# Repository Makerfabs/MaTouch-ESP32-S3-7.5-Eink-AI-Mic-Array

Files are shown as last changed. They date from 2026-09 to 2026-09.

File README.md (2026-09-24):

# MaTouch ESP32-S3 7.5 Eink AI Mic Array

## Introduction

Our MaTouch ESP32-S3 7.5-inch Quad-color E-Ink Display AI Microphone Array Development Board features a 7.5-inch quad-color e-paper display supporting black, white, red, and yellow color rendering. Based on microcapsule electrophoretic display technology, the screen drives charged pigment particles within microcapsules using electric fields, reflecting ambient light to form sharp images that deliver a natural reading experience similar to printed paper.
 
The board is powered by the ESP32-S3R8 main controller, equipped with 8 MB PSRAM and 16 MB SPI Flash. It integrates a four-microphone array and an ES7210 multi-channel audio ADC, enabling multi-channel audio capture for voice recognition, far-field sound pickup, and acoustic algorithm development. Additionally, it includes a QMI8658A six-axis inertial measurement unit providing accelerometer and gyroscope data for motion detection, orientation sensing, and interactive control. The board also features a camera, TF card slot, USB Type-C interface, lithium battery charging circuit, and reserved battery level monitoring functionality, making it ideal for application development in e-paper displays, image capture, voice interaction, and motion sensing.

Product Link: [MaTouch ESP32-S3 7.5 Eink AI Mic Array]

Wiki Link:  [MaTouch ESP32-S3 7.5 Eink AI Mic Array](https://wiki.makerfabs.com/MaTouch%20ESP32_S3%207.5%20Eink%20AI%20Mic%20Array.html)

Example：1.[Camera_display_pic](https://github.com/Makerfabs/MaTouch-ESP32-S3-7.5-Eink-AI-Mic-Array#camera_display_pic)

2.[Voice_EPD_SD_Display](https://github.com/Makerfabs/MaTouch-ESP32-S3-7.5-Eink-AI-Mic-Array#voice_epd_sd_display)

## LCD Specs:

- PART NUMBER:KEGM075004E05
- SIZE:7.5 inch
- TYPE:Dot Matrix
- IC：JD79665
- RESOULUTION:800×480
- OUTLINE SIZE(mm):170.2×135.2×1.111
- ACTIVE SIZE(mm):163.2×97.92
- PIXEL PITCH(mm):0.204×0.204
- OPERATING TEMP:0°C ~ 40°C
- STORAGE TEMP:-25°C ~ 60°C
- CONNECTOR:24 Pin FPC
- COLOR:Black,White,Red,Yellow
- INTERFACE:SPI
- FULL REFRESH(S):20

## Features

- Controller:ESP32-S3
- Wireless:WiFi&Bluetooth 5.0
- Flash:16MB Flash
- PSRAM:8MB
- MICRO SD:Yes
- IMU:QMI8658A
- Camera:OV3660
- Microphone input:4-Microphone Array
- Audio ADC:ES7210
- USB:1*USB_NATIVE
- Arduino support:Yes

## Example

### Camera_display_pic

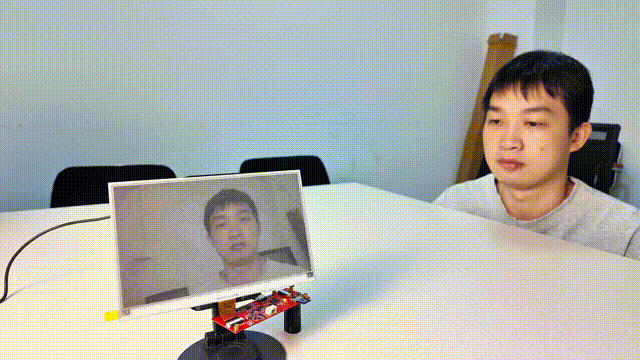
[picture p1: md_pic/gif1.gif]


For details of this example, please refer to the [Wiki](https://wiki.makerfabs.com/MaTouch%20ESP32_S3%207.5%20Eink%20AI%20Mic%20Array.html#41-camera_display_pic) document.

### Voice_EPD_SD_Display

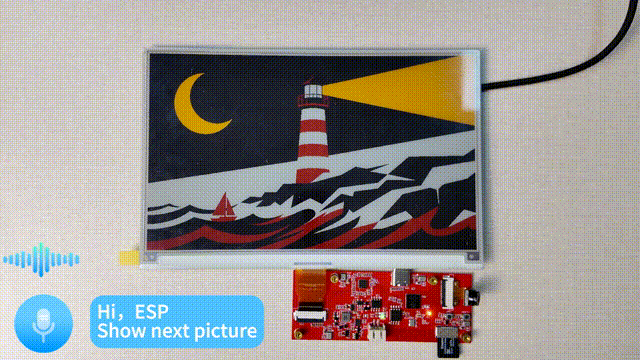
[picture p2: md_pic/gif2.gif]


For details of this example, please refer to the [Wiki](https://wiki.makerfabs.com/MaTouch%20ESP32_S3%207.5%20Eink%20AI%20Mic%20Array.html#42-voice_epd_sd_display) document.

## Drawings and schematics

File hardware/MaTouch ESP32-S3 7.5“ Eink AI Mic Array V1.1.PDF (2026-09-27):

EINK | Mic Array
MIC4P | 28 REFP³⁴ 29 REFQ³⁴ 30

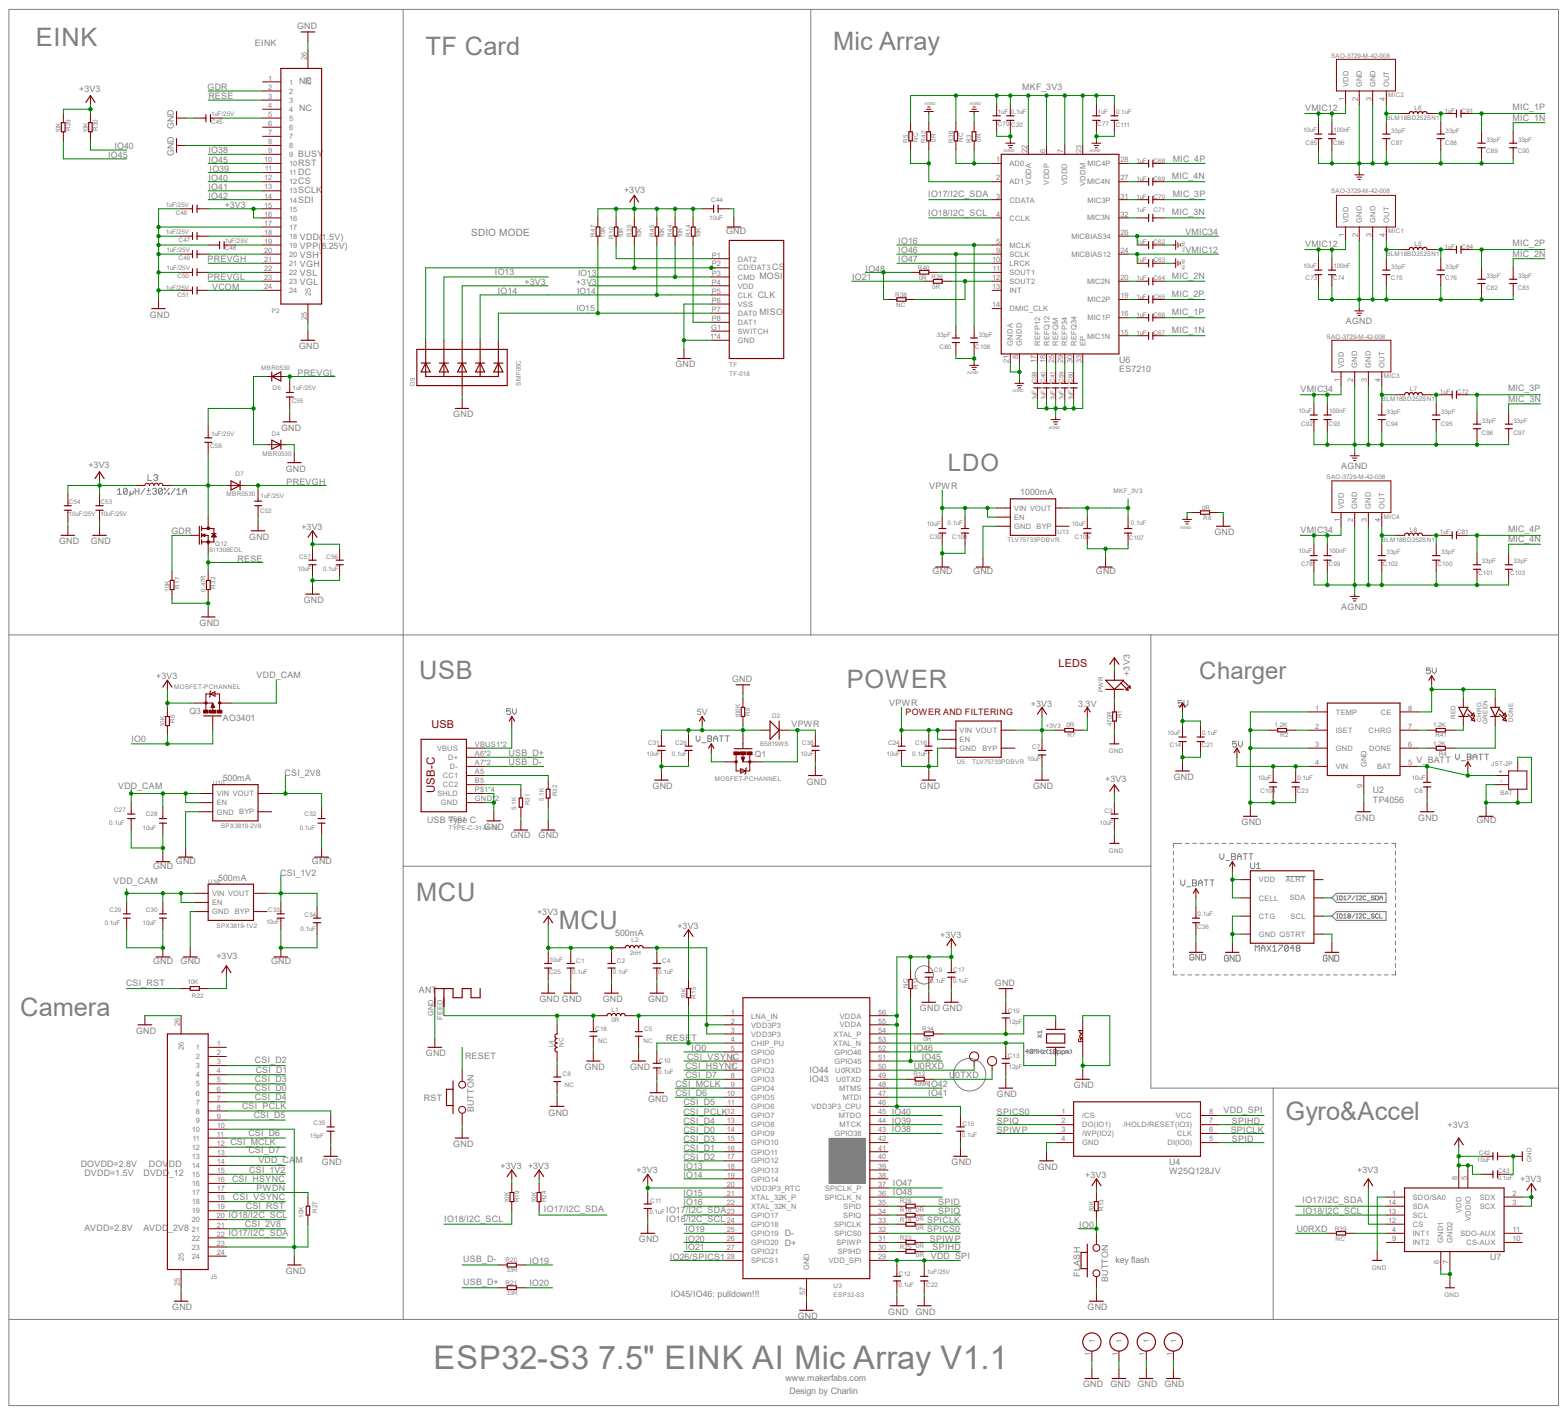
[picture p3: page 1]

SDIO MODE TF Card

key flash ESP32-S3 7.5" EINK AI Mic Array V1.1

GND GND

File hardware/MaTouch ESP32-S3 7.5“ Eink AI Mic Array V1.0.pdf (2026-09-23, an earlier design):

# LDO

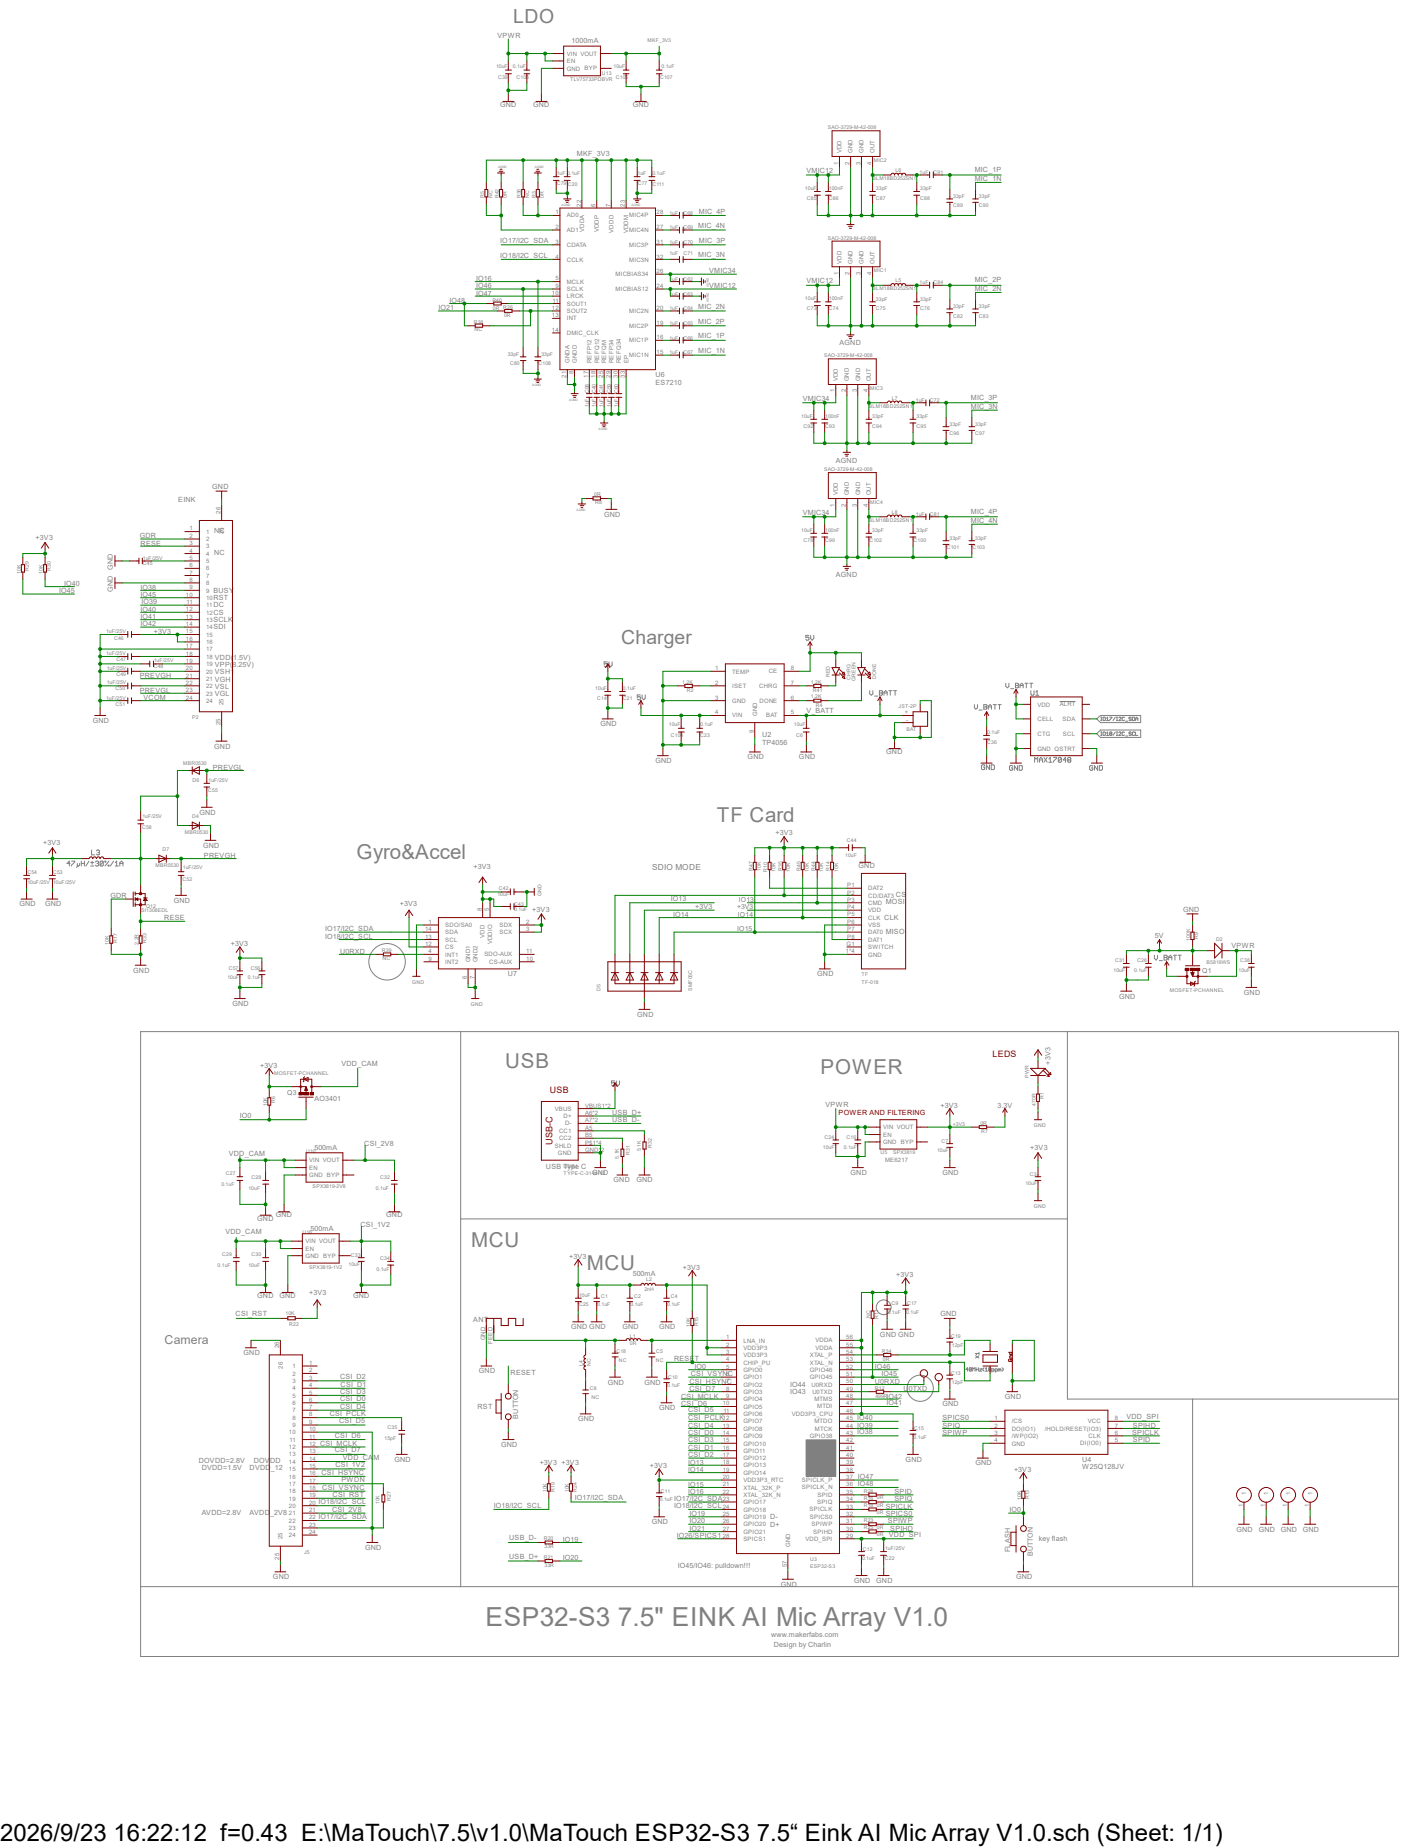
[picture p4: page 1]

RESET C8 NC +3V3 +3V3 | CSI_PCLK CSI_D5 | 2 | 55

GND GND

USB_D-
ESP32-S3 7.5" EINK AI Mic Array V1.0

2026/9/23 16:22:12 f=0.43 E:\MaTouch\7.5\v1.0\MaTouch ESP32-S3 7.5“ Eink AI Mic Array V1.0.sch (Sheet: 1/1)

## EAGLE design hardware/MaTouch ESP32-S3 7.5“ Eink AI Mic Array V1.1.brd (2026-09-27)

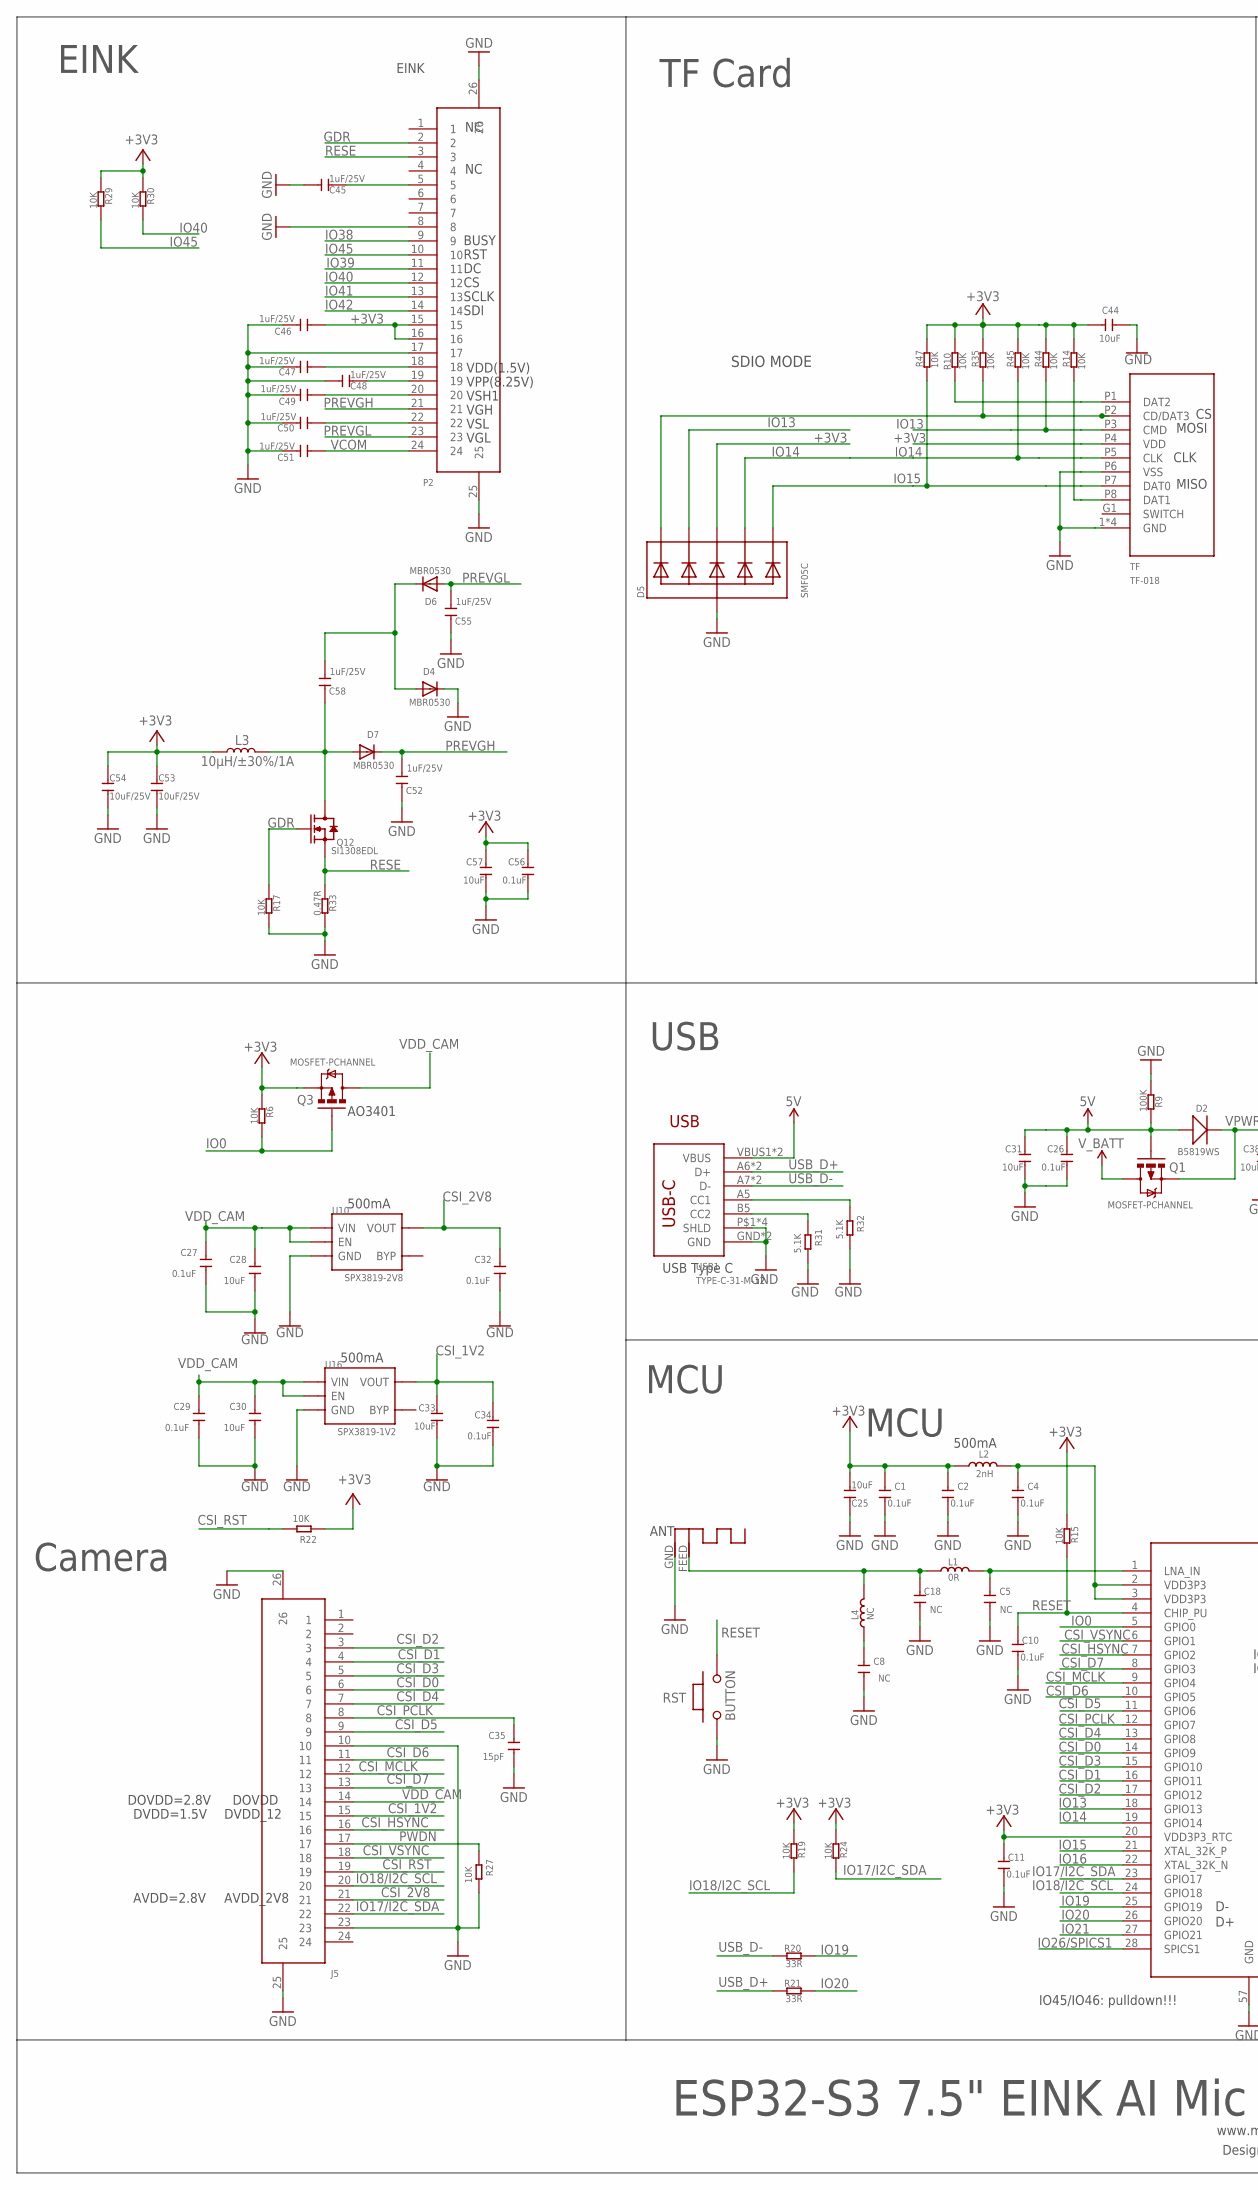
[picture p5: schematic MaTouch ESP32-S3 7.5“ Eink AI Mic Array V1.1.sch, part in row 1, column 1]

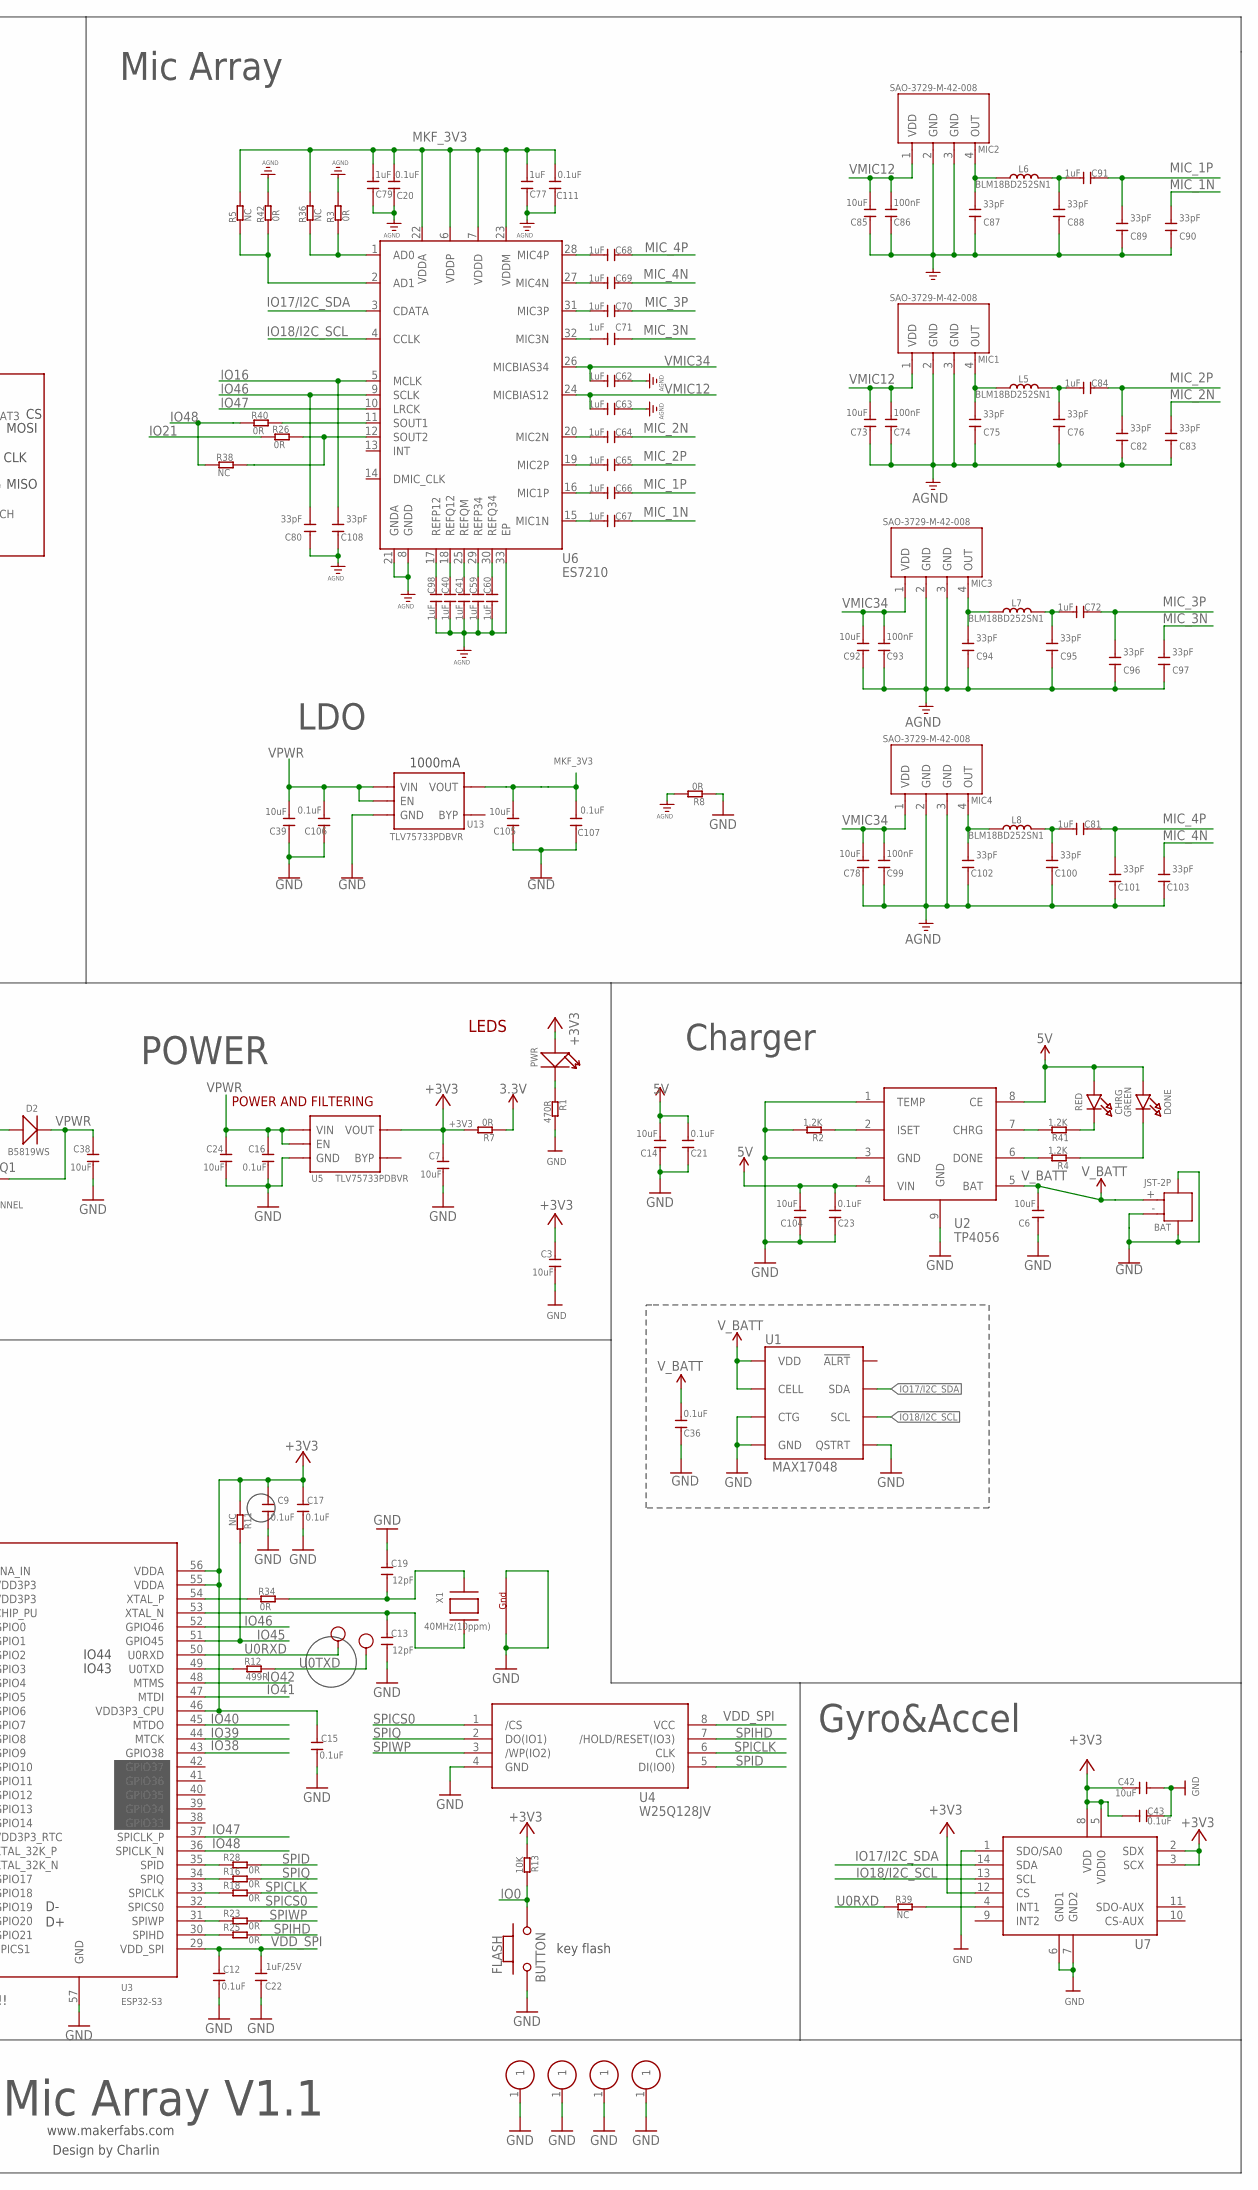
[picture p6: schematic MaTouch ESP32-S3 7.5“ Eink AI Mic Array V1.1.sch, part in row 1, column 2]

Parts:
ANT1: ANTENNA; RN-ANT
BAT: JST-2P; HW2-SMD-2.0-90D
C1, C2, C4, C9, C10, C11, C12, C15, C16, C17, C20, C21, C23, C26, C27, C29, C32, C34, C36, C43, C56, C106, C107, C111: 0.1uF; DISCRETE_C0402
C3, C6, C7, C14, C24, C28, C30, C31, C33, C38, C39, C42, C44, C57, C73, C78, C85, C92, C104, C105: 10uF; DISCRETE_C0402
C5, C8, C18: NC; DISCRETE_C0402
C13, C19: 12pF; DISCRETE_C0402
C22, C45, C46, C47, C48, C49, C50, C51, C52, C55, C58: 1uF/25V; DISCRETE_C0402
C25: 10uF; DISCRETE_C0603
C35: 15pF; DISCRETE_C0402
C40, C41, C59, C60, C62, C63, C64, C65, C66, C67, C68, C69, C70, C71, C72, C77, C79, C81, C84, C91, C98: 1uF; DISCRETE_C0402
C53, C54: 10uF/25V; C0603
C74, C86, C93, C99: 100nF; DISCRETE_C0402
C75, C76, C80, C82, C83, C87, C88, C89, C90, C94, C95, C96, C97, C100, C101, C102, C103, C108: 33pF; DISCRETE_C0402
CHRG: RED; CHIPLED_0805_NOOUTLINE
D2: B5819WS; SOD323
D4, D6, D7: MBR0530; SOD-323F
D5: SMF05C; SOT363
DONE: GREEN; CHIPLED_0805_NOOUTLINE
FLASH: BUTTON; 157SW
J5: FPC-24P; SMD26-50P-1760L450W
L1: 0R; DISCRETE_L0402
L2: 2nH; DISCRETE_L0603
L3: 10µH/±30%/1A; CR54
L4: NC; DISCRETE_L0402
L5, L6, L7, L8: BLM18BD252SN1; L0603
MIC1, MIC2, MIC3, MIC4: SAO-3729-M-42-008; MIC4-SMD-3.76X2.95MM
P2: FPC-24P; SMD26-50P-1760L450W
PWR: DISCRETE_LED0603; DISCRETE_LED-0603
Q1, Q3: MOSFET-PCHANNEL; SOT23-3
Q12: SI1308EDL; SOT23
R1: 470R; DISCRETE_R0402
R2, R4, R41: 1.2K; DISCRETE_R0402
R3, R7, R8, R16, R18, R23, R25, R26, R28, R34, R40, R42: 0R; DISCRETE_R0402
R5, R11, R36, R38, R39: NC; DISCRETE_R0402
R6, R10, R13, R14, R15, R17, R19, R22, R24, R27, R29, R30, R35, R44, R45, R47: 10K; DISCRETE_R0402
R9: 100K; DISCRETE_R0402
R12: 499R; DISCRETE_R0402
R20, R21: 33R; DISCRETE_R0402
R31, R32: 5.1K; DISCRETE_R0402
R33: 0.47R; DISCRETE_R0402
RST: BUTTON; 157SW
RX: TEST-POINT'4545'; TP-D45MIL; PARTNO DNP
S1, S2, S3, S4: ONEPIN01
TF: TF-018
TX: TEST-POINT'4545'; TP-D45MIL; PARTNO DNP
U1: MAX17048; DFN-8
U2: TP4056; SOP8-1.27P
U3: ESP32-S3; QFN56-7*7MM
U4: W25Q128JV; SOIC-8-208MIL
U5, U13: TLV75733PDBVR; SOT23-5
U6: ES7210; QFN33-40P400L400W75H-280X280
U7: QMI8658A; LGA14-50P-300L250W86H
U10: SPX3819-2V8; SOT23-5
U16: SPX3819-1V2; SOT23-5
USB1: TYPE-C-31-M-12
X1: 40MHz(10ppm); NX3225

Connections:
3.3V: R7.2
5V: C14.1, C21.1, C23.1, C26.2, C31.2, C104.1, CHRG.A, D2.+, DONE.A, Q1.1 (G), R9.2, U2.4 (VIN), U2.8 (CE), USB1.VBUS1 (VBUS), USB1.VBUS2 (VBUS)
+3V3: C1.2, C2.2, C3.2, C7.2, C9.2, C11.2, C15.2, C17.2, C25.2, C42.2, C43.2, C44.2, C46.1, C53.1, C54.1, C56.2, C57.2, D5.4 (C3), L2.1, L3.P$1 (1), P2.15, P2.16, PWR.+, Q3.2 (S), R6.2, R7.1, R10.2, R11.2, R13.2, R14.2, R15.2, R19.2, R22.1, R24.2, R29.1, R30.1, R35.2, R44.2, R45.2, R47.2, TF.P4 (VDD), U3.20 (VDD3P3_RTC), U3.46 (VDD3P3_CPU), U3.55 (VDDA), U3.56 (VDDA), U5.5 (VOUT), U7.2 (SDX), U7.3 (SCX), U7.5 (VDDIO), U7.8 (VDD), U7.12 (CS)
AGND: C20.2, C40.2, C41.2, C59.2, C60.2, C62.1, C63.1, C73.2, C74.2, C75.2, C76.2, C77.2, C78.2, C79.2, C80.2, C82.2, C83.2, C85.2, C86.2, C87.2, C88.2, C89.2, C90.2, C92.2, C93.2, C94.2, C95.2, C96.2, C97.2, C98.2, C99.2, C100.2, C101.2, C102.2, C103.2, C108.2, C111.2, MIC1.2 (GND), MIC1.3 (GND), MIC2.2 (GND), MIC2.3 (GND), MIC3.2 (GND), MIC3.3 (GND), MIC4.2 (GND), MIC4.3 (GND), R3.1, R8.1, R42.1, U6.8 (GNDD), U6.21 (GNDA), U6.33 (EP)
CSI_1V2: C33.2, C34.2, J5.15, U16.5 (VOUT)
CSI_2V8: C32.2, J5.21, U10.5 (VOUT)
CSI_D0: J5.6, U3.14 (GPIO9)
CSI_D1: J5.4, U3.16 (GPIO11)
CSI_D2: J5.3, U3.17 (GPIO12)
CSI_D3: J5.5, U3.15 (GPIO10)
CSI_D4: J5.7, U3.13 (GPIO8)
CSI_D5: J5.9, U3.11 (GPIO6)
CSI_D6: J5.11, U3.10 (GPIO5)
CSI_D7: J5.13, U3.8 (GPIO3)
CSI_HSYNC: J5.16, U3.7 (GPIO2)
CSI_MCLK: J5.12, U3.9 (GPIO4)
CSI_PCLK: C35.2, J5.8, U3.12 (GPIO7)
CSI_RST: J5.19, R22.2
CSI_VSYNC: J5.18, U3.6 (GPIO1)
GDR: P2.2, Q12.1 (G), R17.1
GND: ANT1.GND, BAT.3, BAT.4, BAT.- (2), C1.1, C2.1, C3.1, C4.1, C5.1, C6.2, C7.1, C8.1, C9.1, C10.1, C11.1, C12.1, C13.1, C14.2, C15.1, C16.1, C17.1, C18.1, C19.2, C21.2, C22.2, C23.2, C24.1, C25.1, C26.1, C27.1, C28.1, C29.1, C30.1, C31.1, C32.1, C33.1, C34.1, C35.1, C36.2, C38.1, C39.2, C42.1, C43.1, C44.1, C45.2, C46.2, C47.2, C48.2, C49.2, C50.2, C51.2, C52.2, C53.2, C54.2, C55.2, C56.1, C57.1, C104.2, C105.2, C106.2, C107.2, D4.C, D5.2 (A), FLASH.1, J5.10, J5.23, J5.25, J5.26, P2.8, P2.17, P2.25, P2.26, R1.1, R2.1, R8.2, R9.1, R17.2, R27.2, R31.2, R32.2, R33.2, RST.1, S1.1, S2.1, S3.1, S4.1, TF.1 (GND), TF.2 (GND), TF.3 (GND), TF.4 (GND), TF.P6 (VSS), U1.1 (CTG), U1.4 (GND), U1.6 (QSTRT), U1.9 (GND), U2.1 (TEMP), U2.3 (GND), U2.9 (GND), U3.57 (GND), U4.4 (GND), U5.2 (GND), U7.1 (SDO/SA0), U7.6 (GND1), U7.7 (GND2), U10.2 (GND), U13.2 (GND), U16.2 (GND), USB1.GND, USB1.GND2 (GND), USB1.P$1 (SHLD), USB1.P$2 (SHLD), USB1.P$3 (SHLD), USB1.P$4 (SHLD), X1.2 (G2), X1.4 (G1)
IO0: FLASH.2, Q3.1 (G), R6.1, R13.1, U3.5 (GPIO0)
IO13: D5.3 (C2), R44.1, TF.P3 (CMD), U3.18 (GPIO13)
IO14: D5.5 (C4), R45.1, TF.P5 (CLK), U3.19 (GPIO14)
IO15: D5.6 (C5), R47.1, TF.P7 (DAT0), U3.21 (XTAL_32K_P)
IO16: C108.1, U3.22 (XTAL_32K_N), U6.5 (MCLK)
IO17/I2C_SDA: J5.22, R24.1, U1.8 (SDA), U3.23 (GPIO17), U6.3 (CDATA), U7.14 (SDA)
IO18/I2C_SCL: J5.20, R19.1, U1.7 (SCL), U3.24 (GPIO18), U6.4 (CCLK), U7.13 (SCL)
IO19: R20.1, U3.25 (GPIO19)
IO20: R21.1, U3.26 (GPIO20)
IO21: R26.2, U3.27 (GPIO21)
IO26/SPICS1: U3.28 (SPICS1)
IO38: P2.9, U3.43 (GPIO38)
IO39: P2.11, U3.44 (MTCK)
IO40: P2.12, R30.2, U3.45 (MTDO)
IO41: P2.13, U3.47 (MTDI)
IO42: P2.14, U3.48 (MTMS)
IO45: P2.10, R11.1, R29.2, U3.51 (GPIO45)
IO46: C80.1, U3.52 (GPIO46), U6.9 (SCLK)
IO47: U3.37 (SPICLK_P), U6.10 (LRCK)
IO48: R38.2, R40.2, U3.36 (SPICLK_N)
MIC_1N: C67.1, C90.1
MIC_1P: C66.1, C89.1, C91.1
MIC_2N: C64.1, C83.1
MIC_2P: C65.1, C82.1, C84.1
MIC_3N: C71.1, C97.1
MIC_3P: C70.1, C72.1, C96.1
MIC_4N: C69.1, C103.1
MIC_4P: C68.1, C81.1, C101.1
MKF_3V3: C20.1, C77.1, C79.1, C105.1, C107.1, C111.1, R5.1, R36.1, U6.6 (VDDP), U6.7 (VDDD), U6.22 (VDDA), U6.23 (VDDM), U13.5 (VOUT)
unnamed: ANT1.FEED, C18.2, L1.1, L4.2
unnamed: C5.2, L1.2, U3.1 (LNA_IN)
unnamed: R28.2, U3.35 (SPID)
unnamed: C8.2, L4.1
unnamed: R32.1, USB1.A5 (CC1)
unnamed: C45.1, P2.5
unnamed: PWR.-, R1.2
unnamed: C48.1, P2.19
unnamed: C49.1, P2.20
unnamed: C50.1, P2.22
unnamed: C58.1, D4.A, D6.C
unnamed: R2.2, U2.2 (ISET)
unnamed: R41.1, U2.7 (CHRG)
unnamed: R4.1, U2.6 (DONE)
unnamed: CHRG.C, R41.2
unnamed: DONE.C, R4.2
unnamed: C98.1, U6.17 (REFP12)
unnamed: C40.1, U6.18 (REFQ12)
unnamed: C41.1, U6.25 (REFQM)
unnamed: C59.1, U6.29 (REFP34)
unnamed: R10.1, TF.P1 (DAT2)
unnamed: C47.1, P2.18
unnamed: C60.1, U6.30 (REFQ34)
unnamed: C67.2, U6.15 (MIC1N)
unnamed: C66.2, U6.16 (MIC1P)
unnamed: C64.2, U6.20 (MIC2N)
unnamed: C70.2, U6.31 (MIC3P)
unnamed: R14.1, TF.P8 (DAT1)
unnamed: D5.1 (C1), R35.1, TF.P2 (CD/DAT3)
unnamed: C65.2, U6.19 (MIC2P)
unnamed: C76.1, C84.2, L5.2
unnamed: R3.2, R36.2, U6.1 (AD0)
unnamed: C4.2, L2.2, U3.2 (VDD3P3), U3.3 (VDD3P3)
unnamed: R31.1, USB1.B5 (CC2)
unnamed: R16.2, U3.34 (SPIQ)
unnamed: R40.1, U6.11 (SOUT1)
unnamed: R34.2, U3.54 (XTAL_P)
unnamed: R18.2, U3.33 (SPICLK)
unnamed: C71.2, U6.32 (MIC3N)
unnamed: R23.2, U3.31 (SPIWP)
unnamed: R25.2, U3.30 (SPIHD)
unnamed: R39.1, U7.4 (INT1)
unnamed: C75.1, L5.1, MIC1.4 (OUT)
unnamed: C88.1, C91.2, L6.2
unnamed: C87.1, L6.1, MIC2.4 (OUT)
unnamed: C69.2, U6.27 (MIC4N)
unnamed: C81.2, C100.1, L8.2
unnamed: C72.2, C95.1, L7.2
unnamed: C68.2, U6.28 (MIC4P)
unnamed: R26.1, R38.1, U6.12 (SOUT2)
unnamed: C94.1, L7.1, MIC3.4 (OUT)
unnamed: R5.2, R42.2, U6.2 (AD1)
unnamed: R12.2, U3.49 (U0TXD)
unnamed: C13.2, U3.53 (XTAL_N), X1.3 (X2)
unnamed: C19.1, R34.1, X1.1 (X1)
unnamed: C102.1, L8.1, MIC4.4 (OUT)
unnamed: C58.2, D7.A, L3.P$2 (2), Q12.3 (D)
PREVGH: C52.1, D7.C, P2.21
PREVGL: C55.1, D6.A, P2.23
PWDN: J5.17, R27.1
RESE: P2.3, Q12.2 (S), R33.1
RESET: C10.2, R15.1, RST.2, U3.4 (CHIP_PU)
SPICLK: R18.1, U4.6 (CLK)
SPICS0: U3.32 (SPICS0), U4.1 (/CS)
SPID: R28.1, U4.5 (DI(IO0))
SPIHD: R25.1, U4.7 (/HOLD/RESET(IO3))
SPIQ: R16.1, U4.2 (DO(IO1))
SPIWP: R23.1, U4.3 (/WP(IO2))
U0RXD: R39.2, RX.T, U3.50 (U0RXD)
U0TXD: R12.1, TX.T
USB_D+: R21.2, USB1.A6 (D+), USB1.B6 (D+)
USB_D-: R20.2, USB1.A7 (D-), USB1.B7 (D-)
VCOM: C51.1, P2.24
VDD_CAM: C27.2, C28.2, C29.2, C30.2, J5.14, Q3.3 (D), U10.1 (VIN), U10.3 (EN), U16.1 (VIN), U16.3 (EN)
VDD_SPI: C12.2, C22.1, U3.29 (VDD_SPI), U4.8 (VCC)
VMIC12: C63.2, C73.1, C74.1, C85.1, C86.1, MIC1.1 (VDD), MIC2.1 (VDD), U6.24 (MICBIAS12)
VMIC34: C62.2, C78.1, C92.1, C93.1, C99.1, MIC3.1 (VDD), MIC4.1 (VDD), U6.26 (MICBIAS34)
VPWR: C16.2, C24.2, C38.2, C39.1, C106.1, D2.-, Q1.2 (S), U5.1 (VIN), U5.3 (EN), U13.1 (VIN), U13.3 (EN)
V_BATT: BAT.+ (1), C6.1, C36.1, Q1.3 (D), U1.2 (CELL), U1.3 (VDD), U2.5 (BAT)

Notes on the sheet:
www.makerfabs.com
Design by Charlin
LEDS
POWER AND FILTERING
key flash
ESP32-S3 7.5" EINK AI Mic Array V1.1
POWER
MCU
500mA
IO45/IO46: pulldown!!!
IO43
IO44
ANT
USB
DVDD=1.5V
AVDD=2.8V
DOVDD=2.8V
Camera
AVDD_2V8
DVDD_12
DOVDD
USB Type C
AO3401
Gyro&Accel
SDIO MODE
TF Card
MOSI
CLK
MISO
EINK
VDD(1.5V)
VPP(8.25V)
VSH1
VGH
VSL
VGL
BUSY
RST
SCLK
SDI

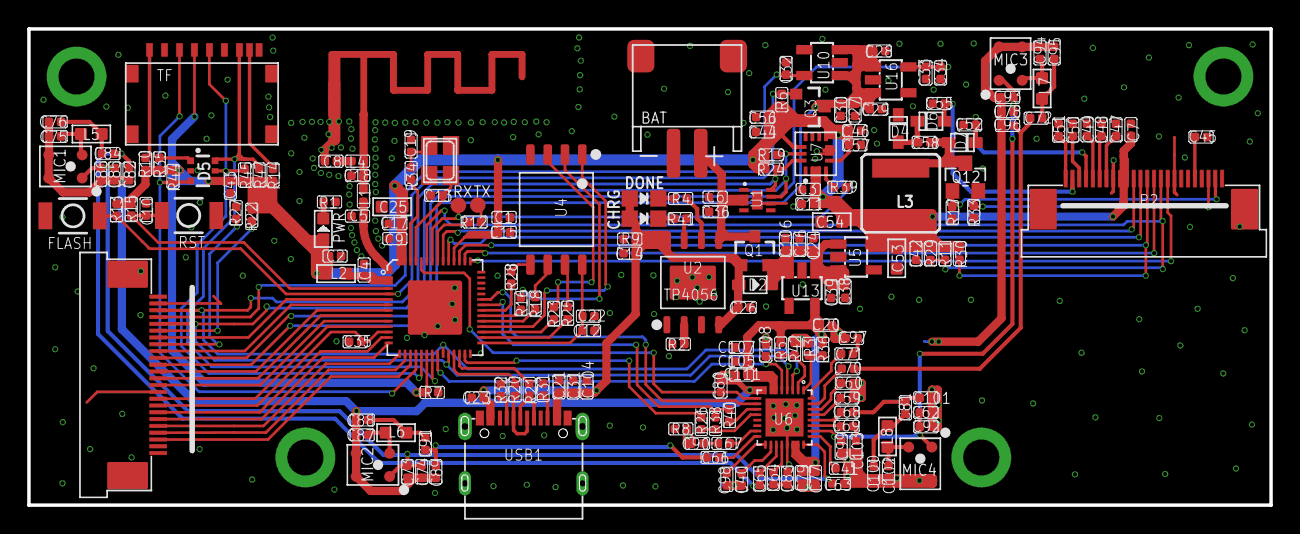
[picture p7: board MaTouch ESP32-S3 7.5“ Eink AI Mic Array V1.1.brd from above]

Board: 2 copper layers, 91.3 x 35.0 mm, 200 parts (1 on the bottom side), 127 nets.

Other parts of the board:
U$1: MAKERFABS_0.3

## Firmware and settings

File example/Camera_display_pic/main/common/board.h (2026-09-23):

#pragma once

#include "driver/gpio.h"

#define BOARD_CAMERA_POWER GPIO_NUM_0
#define BOARD_CAMERA_XCLK GPIO_NUM_4
#define BOARD_CAMERA_PCLK GPIO_NUM_7
#define BOARD_CAMERA_VSYNC GPIO_NUM_1
#define BOARD_CAMERA_HREF GPIO_NUM_2
#define BOARD_CAMERA_D0 GPIO_NUM_9
#define BOARD_CAMERA_D1 GPIO_NUM_11
#define BOARD_CAMERA_D2 GPIO_NUM_12
#define BOARD_CAMERA_D3 GPIO_NUM_10
#define BOARD_CAMERA_D4 GPIO_NUM_8
#define BOARD_CAMERA_D5 GPIO_NUM_6
#define BOARD_CAMERA_D6 GPIO_NUM_5
#define BOARD_CAMERA_D7 GPIO_NUM_3
#define BOARD_CAMERA_SDA GPIO_NUM_17
#define BOARD_CAMERA_SCL GPIO_NUM_18

#define BOARD_EPD_BUSY GPIO_NUM_38
#define BOARD_EPD_RST GPIO_NUM_45
#define BOARD_EPD_DC GPIO_NUM_39
#define BOARD_EPD_CS GPIO_NUM_40
#define BOARD_EPD_SCLK GPIO_NUM_41
#define BOARD_EPD_MOSI GPIO_NUM_42

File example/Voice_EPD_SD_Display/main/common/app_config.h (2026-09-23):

#pragma once

#define APP_STORAGE_MOUNT_POINT "/sdcard"
#define APP_IMAGE_DIRECTORY APP_STORAGE_MOUNT_POINT "/images"
#define APP_MAX_IMAGES 128

#define APP_AUDIO_SAMPLE_RATE_HZ 16000
#define APP_AUDIO_CAPTURE_CHANNELS 2
#define APP_AUDIO_CHANNELS 2

#define APP_COMMAND_PREVIOUS_ID 1
#define APP_COMMAND_NEXT_ID 2
#define APP_COMMAND_PREVIOUS_PHRASE "show previous picture"
#define APP_COMMAND_NEXT_PHRASE "show next picture"
#define APP_COMMAND_TIMEOUT_MS 6000
#define APP_COMMAND_DEBOUNCE_MS 1200
#define APP_WAKE_WORD "Hi ESP"
#define APP_WAKE_COMMAND_WINDOW_MS 8000

#define APP_VAD_TRAILING_AUDIO_MS 768
#define APP_VAD_MIN_SPEECH_MS 128
#define APP_VAD_MIN_NOISE_MS 450
#define APP_VAD_DELAY_MS 192

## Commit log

2026-09-23 Add code
    [MaTouch ESP32-S3 7.5“ Eink AI Mic Array V1.0.brd, MaTouch ESP32-S3 7.5“ Eink AI Mic Array V1.0.sch, partitions.csv]
2026-09-27 Add hardware
    [MaTouch ESP32-S3 7.5“ Eink AI Mic Array V1.1.brd, MaTouch ESP32-S3 7.5“ Eink AI Mic Array V1.1.sch]

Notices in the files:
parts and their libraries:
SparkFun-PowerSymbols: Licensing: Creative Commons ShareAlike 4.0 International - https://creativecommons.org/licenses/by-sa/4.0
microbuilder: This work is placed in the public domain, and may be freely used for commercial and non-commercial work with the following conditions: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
